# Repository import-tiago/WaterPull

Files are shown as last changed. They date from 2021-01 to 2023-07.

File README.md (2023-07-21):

# Water Pull
WaterPull is an electronic polymer dryer focused on removing moisture from 3D printer filaments. It has control and adjustment of temperature and curing time, internal air circulation and alarms.

## PCB Preview
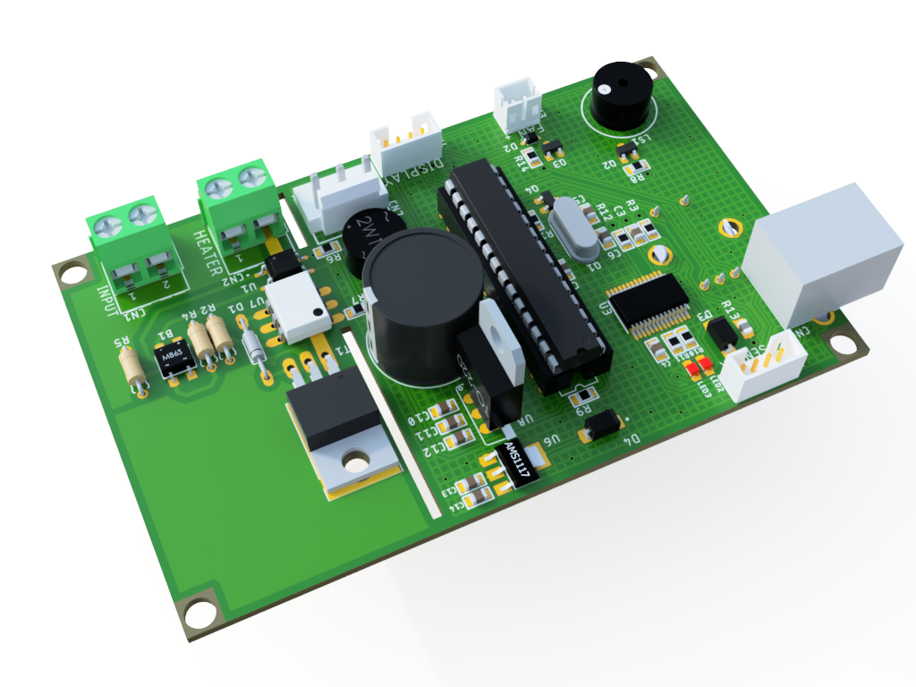
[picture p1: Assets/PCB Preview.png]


## Enclosure Preview
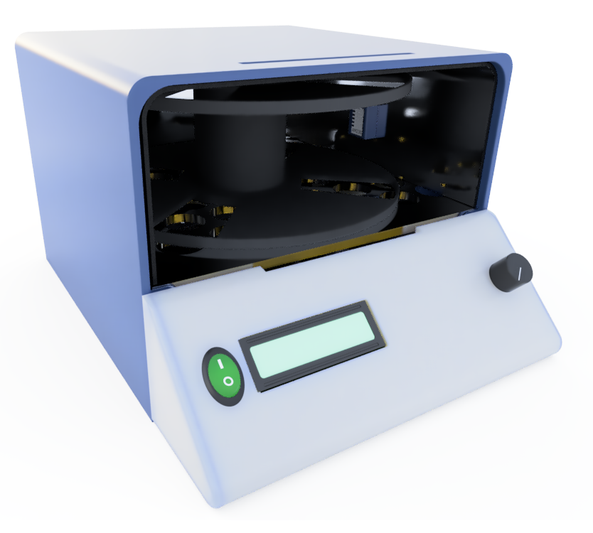
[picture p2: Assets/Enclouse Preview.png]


## Schematic
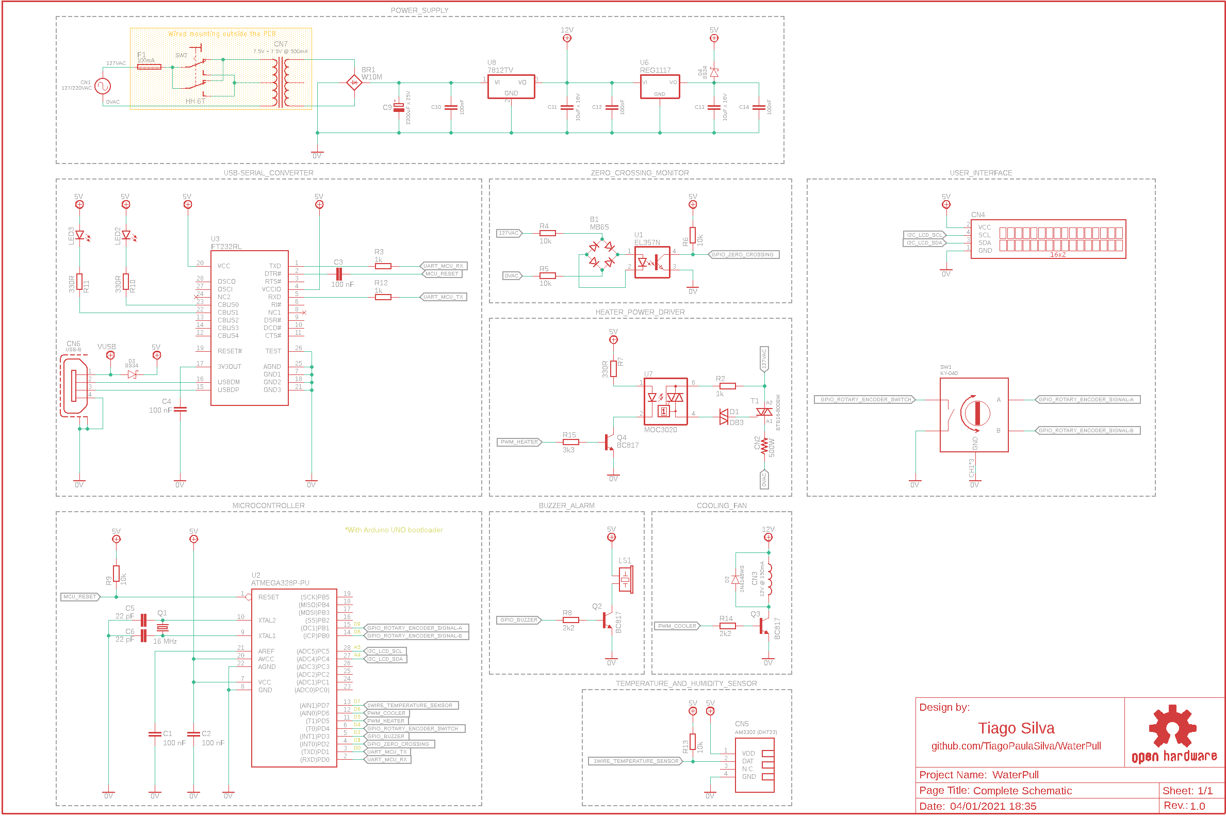
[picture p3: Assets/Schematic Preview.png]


### Contributing
0. Give this project a :star:
1. Create an issue and describe your idea.
2. [Fork it](https://github.com/import-tiago/WaterPull/fork).
3. Create your feature branch (`git checkout -b my-new-feature`).
4. Commit your changes (`git commit -a -m "Added feature title"`).
5. Publish the branch (`git push origin my-new-feature`).
6. Create a new pull request.
7. Done! :heavy_check_mark:

### License Information
<br /><span xmlns:dct="http://purl.org/dc/terms/" property="dct:title">ChristmasTree</span> by <a xmlns:cc="http://creativecommons.org/ns#" href="https://github.com/import-tiago" property="cc:attributionName" rel="cc:attributionURL">Tiago Silva</a> is licensed under a <a rel="license" href="http://creativecommons.org/licenses/by-sa/4.0/">Creative Commons Attribution-ShareAlike 4.0 International License</a>.<br />Permissions beyond the scope of this license may be available at <a xmlns:cc="http://creativecommons.org/ns#" href="https://twitter.com/import_tiago" rel="cc:morePermissions">tiagodepaulasilva@gmail.com</a>.

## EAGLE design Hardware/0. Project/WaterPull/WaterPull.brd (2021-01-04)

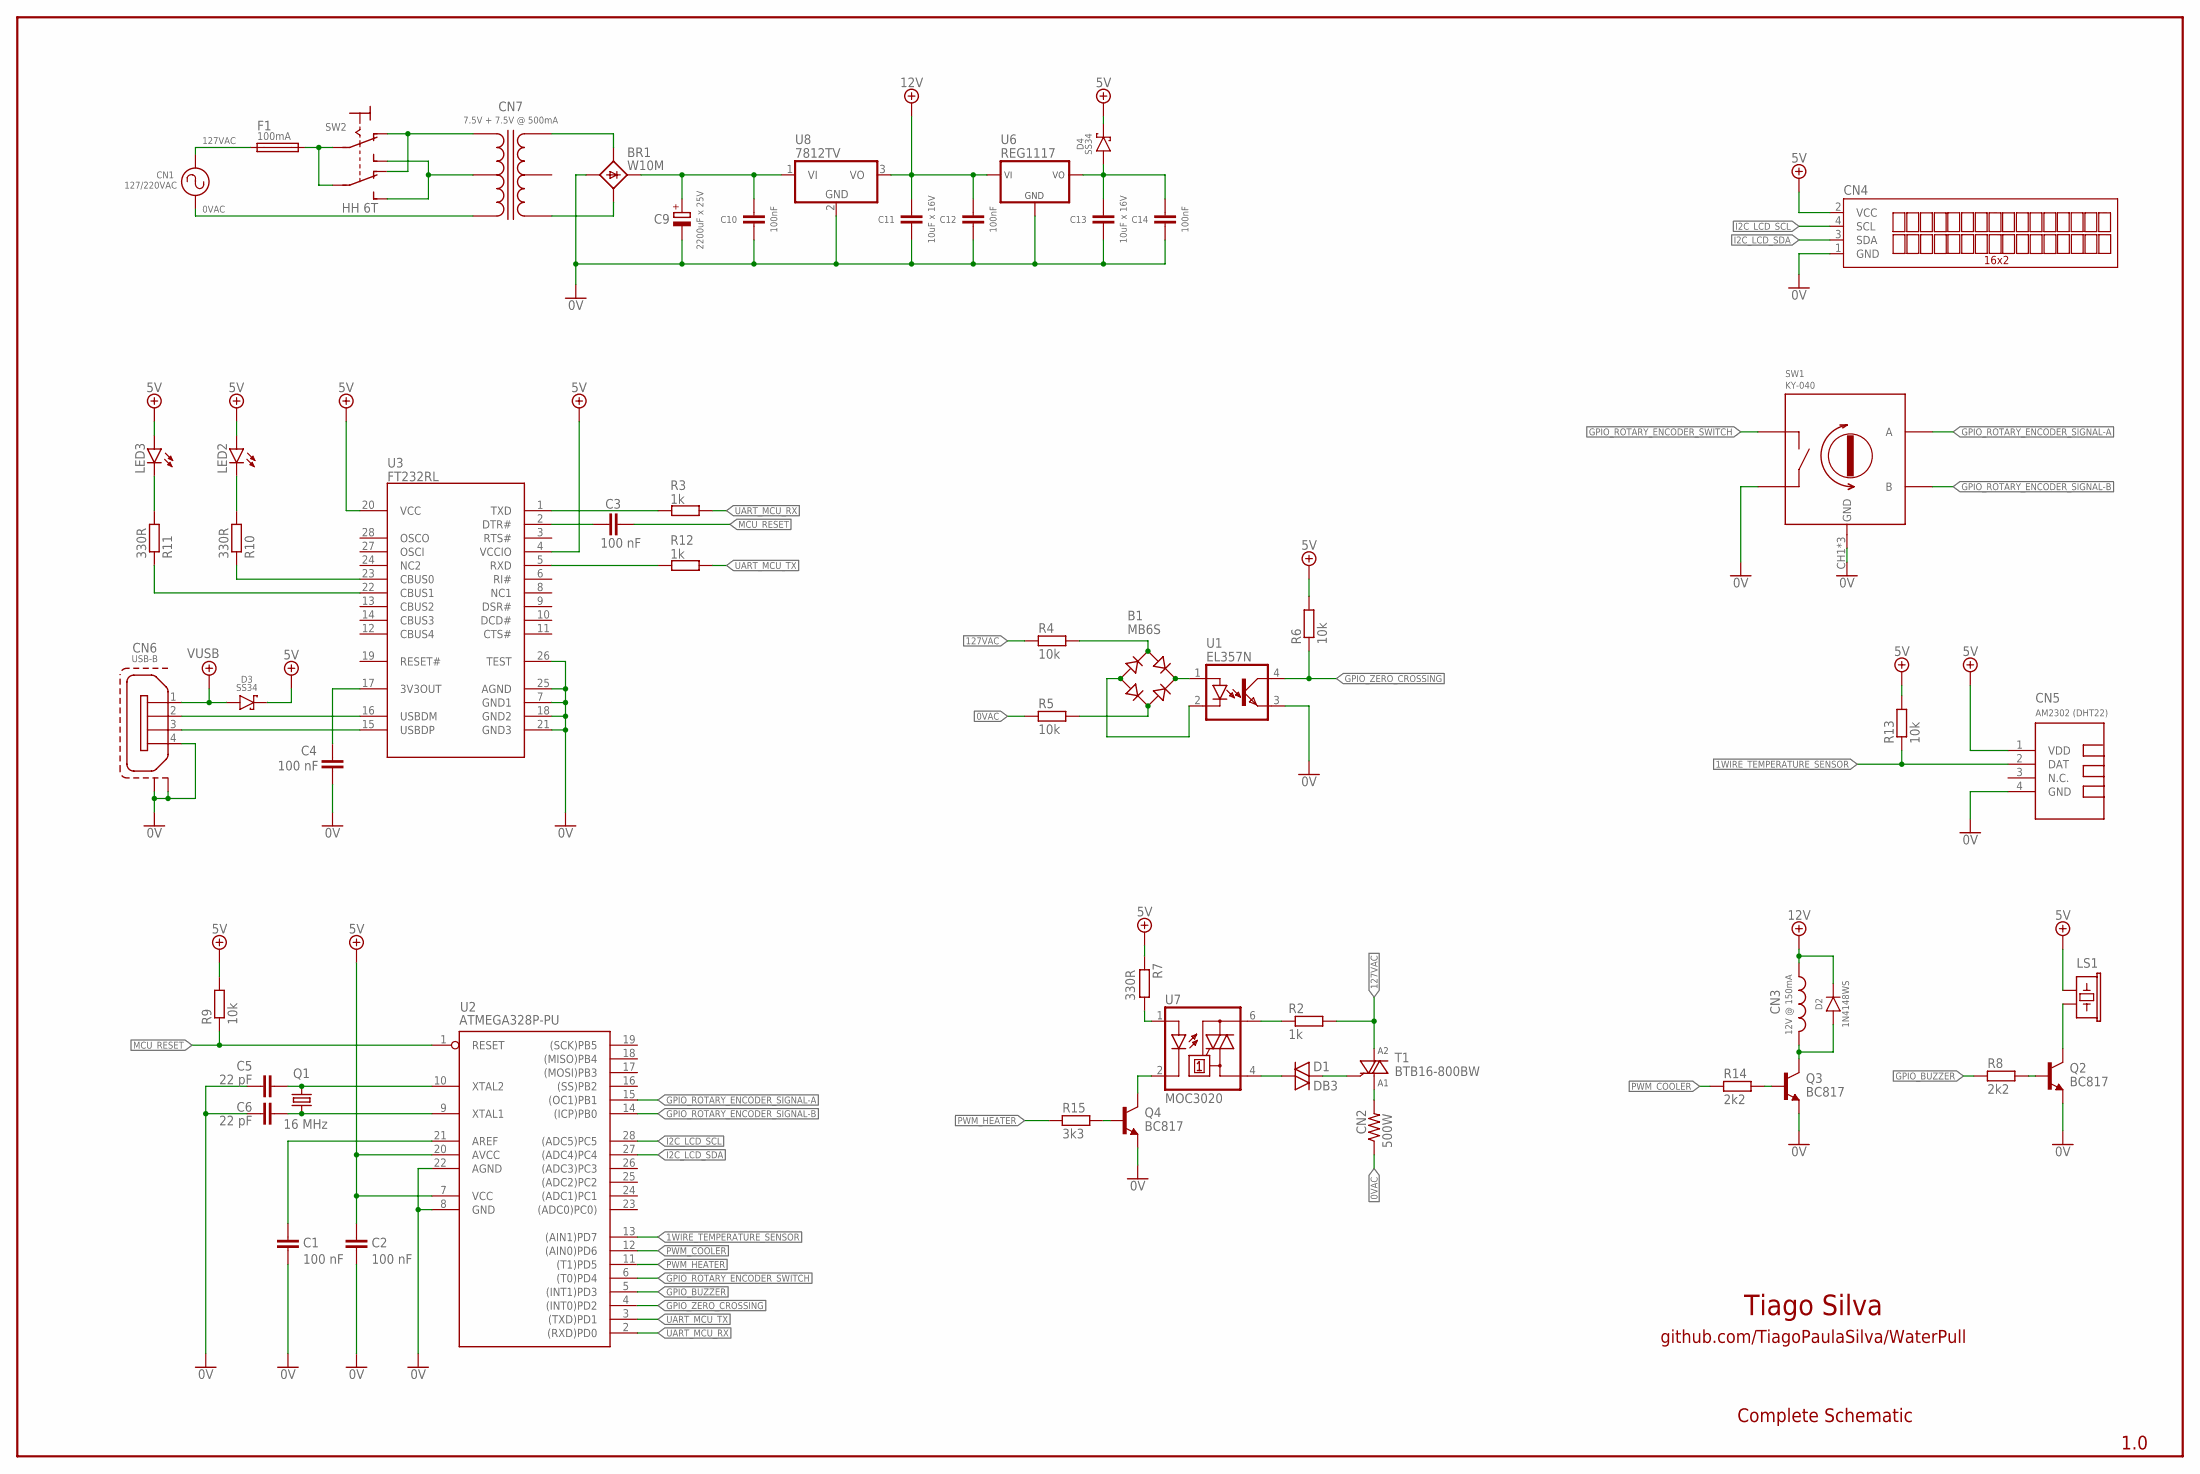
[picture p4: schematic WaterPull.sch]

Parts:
B1: MB6S; SOIC-4
BR1: W10M; DIOB_W005M
C1, C2, C3, C4: 100 nF; C0805
C5, C6: 22 pF; C0805
C9: 2200uF x 25V; E7,5-16
C10, C12, C14: 100nF; C0805
C11, C13: 10uF x 16V; C0805
CN1: 127/220VAC; AK500/2-H
CN2: 500W; AK500/2-H
CN3: 12V @ 150mA; JST-PH2
CN4: TUXGR_16X2_R2
CN5: AM2302 (DHT22); TEMP-HUM-SENSOR-DHT22
CN6: USB-B
CN7: 7.5V + 7.5V @ 500mA; 3PINS
D1: DB3; DO35-10
D2: 1N4148WS; SOD323F
D3, D4: SS34; DO214AB
LED2, LED3: LEDCHIPLED_0805; CHIPLED_0805
LS1: BUZZER-PTH; BUZZER-12MM
Q1: 16 MHz; HC49/S
Q2, Q3, Q4: BC817; SOT23-BEC
R2: 1k; 0207/7
R3, R12: 1k; R0805
R4, R5: 10k; 0207/7
R6, R9, R13: 10k; R0805
R7, R10, R11: 330R; R0805
R8, R14: 2k2; R0805
R15: 3k3; R0805
SW1: KY-040
T1: BTB16-800BW; TO220BH
U1: EL357N; SOP254P700X200-4N
U2: ATMEGA328P-PU; DIL28-3
U3: FT232RL; SSOP28
U6: REG1117; SOT223
U7: MOC3020; DIL06
U8: 7812TV; TO220V

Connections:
0V: BR1.-, C1.2, C2.2, C4.1, C5.1, C6.1, C9.-, C10.2, C11.2, C12.2, C13.2, C14.2, CN4.1 (GND), CN5.4 (GND), CN6.4, CN6.M1 (S1), CN6.M2 (S2), Q2.E, Q3.E, Q4.E, SW1.CH1 (GND), SW1.CH2 (GND), SW1.GND, SW1.SW2, U1.3 (E), U2.8 (GND), U2.22 (AGND), U3.7 (GND1), U3.18 (GND2), U3.21 (GND3), U3.25 (AGND), U3.26 (TEST), U6.1 (GND), U8.2 (GND)
0VAC: CN1.1, CN2.1, R5.1
1WIRE_TEMPERATURE_SENSOR: CN5.2 (DAT), R13.1, U2.13 ((AIN1)PD7)
5V: C2.1, CN4.2 (VCC), CN5.1 (VDD), D3.C (K), D4.C (K), LED2.A, LED3.A, LS1.+ (1), R6.2, R7.1, R9.2, R13.2, U2.7 (VCC), U2.20 (AVCC), U3.4 (VCCIO), U3.20 (VCC)
12VDC: C11.1, C12.1, CN3.2 (1), D2.C (K), U6.3 (VIN), U8.3 (VO)
127VAC: CN1.2, R2.2, R4.1, T1.T2 (A2)
A1: CN2.2, T1.T1 (A1)
AREF: C1.1, U2.21 (AREF)
GND1: BR1.~B (AC2), CN7.3
GPIO_BUZZER: R8.1, U2.5 ((INT1)PD3)
GPIO_ROTARY_ENCODER_SIGNAL-A: SW1.A, U2.15 ((OC1)PB1)
GPIO_ROTARY_ENCODER_SIGNAL-B: SW1.B, U2.14 ((ICP)PB0)
GPIO_ROTARY_ENCODER_SWITCH: SW1.SW1, U2.6 ((T0)PD4)
GPIO_ZERO_CROSSING: R6.1, U1.4 (C), U2.4 ((INT0)PD2)
I2C_LCD_SCL: CN4.4 (SCL), U2.28 ((ADC5)PC5)
I2C_LCD_SDA: CN4.3 (SDA), U2.27 ((ADC4)PC4)
MCU_RESET: C3.1, R9.1, U2.1 (RESET)
unnamed: D1.A (1), U7.4 (A1)
unnamed: D1.C (2), T1.G
unnamed: B1.~1 (AC1), R4.2
unnamed: B1.~2 (AC2), R5.2
unnamed: B1.+, U1.1 (A)
unnamed: B1.-, U1.2 (K)
unnamed: R3.2, U3.1 (TXD)
unnamed: R2.1, U7.6 (A2)
unnamed: R7.2, U7.1 (A)
unnamed: LS1.- (2), Q2.C
unnamed: R12.2, U3.5 (RXD)
unnamed: BR1.+, C9.+, C10.1, U8.1 (VI)
unnamed: Q4.B, R15.2
unnamed: Q4.C, U7.2 (C)
unnamed: C13.1, C14.1, D4.A, U6.2 (VOUT), U6.4 (VOUT)
unnamed: C3.2, U3.2 (DTR#)
unnamed: R10.1, U3.23 (CBUS0)
unnamed: LED2.C, R10.2
unnamed: LED3.C, R11.2
unnamed: C5.2, Q1.2, U2.10 (XTAL2)
unnamed: C6.2, Q1.1, U2.9 (XTAL1)
unnamed: R11.1, U3.22 (CBUS1)
unnamed: C4.2, U3.17 (3V3OUT)
unnamed: CN6.2, U3.16 (USBDM)
unnamed: CN6.3, U3.15 (USBDP)
unnamed: Q2.B, R8.2
unnamed: CN3.1 (2), D2.A, Q3.C
unnamed: Q3.B, R14.2
unnamed: BR1.~A (AC1), CN7.1
PWM_COOLER: R14.1, U2.12 ((AIN0)PD6)
PWM_HEATER: R15.1, U2.11 ((T1)PD5)
UART_MCU_RX: R3.1, U2.2 ((RXD)PD0)
UART_MCU_TX: R12.1, U2.3 ((TXD)PD1)
VUSB: CN6.1, D3.A

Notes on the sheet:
Tiago Silva
github.com/TiagoPaulaSilva/WaterPull
1.0
Complete Schematic

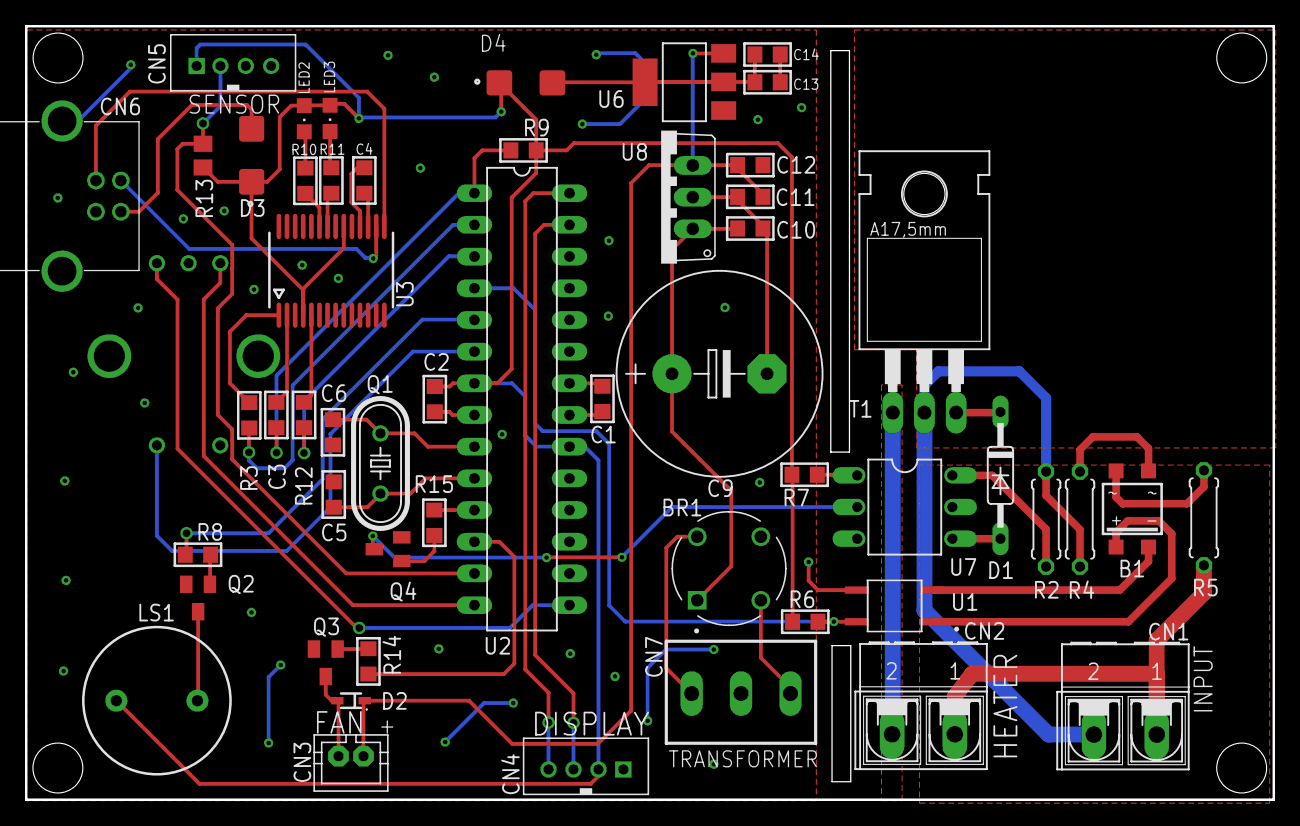
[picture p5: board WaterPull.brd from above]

Board: 2 copper layers, 100.0 x 62.0 mm, 54 parts (1 on the bottom side), 51 nets.

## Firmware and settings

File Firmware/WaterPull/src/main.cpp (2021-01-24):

// Native Libraries
#include <Arduino.h>

// ANSI C Libraries
#include <stdlib.h>

// Application Libraries
#include <RotaryEncoder.h>
#include <TimerOne.h>
#include "Adafruit_Sensor.h"
#include <DHT.h>
#include <LiquidCrystal_I2C.h>

// Hardware Definitions
#define Temperature_Sensor_Pin 7

#define Rotary_Enconder_Clock_Pin   8
#define Rotary_Enconder_Data_Pin 	9
#define Rotary_Enconder_Switch_Pin  4
#define Zero_Crossing_Pin 			2	
#define Buzzer_Pin 					3
#define Heater_Pin 					5
#define Cooler_Pin 					6
#define Zero_Crossing_Interrupt     0



// Application Constants
#define STARTING_MESSAGE_TIME 250
#define TEXT_BLINK_TIME 	  300
#define ARROW_DOWN 			  0
#define ARROW_RIGHT 		  1

#define SOUND_ALARM_NUMBER_BEEP 	  3
#define SOUND_ALARM_PERIOD_BEEP 	  400



// Global Objects
RotaryEncoder RotaryEnconder(Rotary_Enconder_Data_Pin, Rotary_Enconder_Clock_Pin);
DHT AmbientSensor(Temperature_Sensor_Pin, DHT22);
LiquidCrystal_I2C LCD(0x27, 16, 2); //I2C address = 0x27

// Global Variables
int Last_Rotary_Position = 0;
float Current_Humidity = 0;
float Current_Temperature = 0;
unsigned int Current_Cure_Time = 0;

float Setpoint_Temperature = 50;
unsigned int Setpoint_Cure_Time = 180;

unsigned long Current_Millis = 0;
unsigned long Previous_Millis = 0;
unsigned long ISR_Tick = 0;

volatile int Current_Rotary_Position = 0;


volatile boolean zero_cross = false;

int Heater_Power = 1; //0-255 (duty cycle)


bool Toggle = false;

bool increment = false;


byte button;

// LCD
byte DownArrow[] = {
	B00100,
	B00100,
	B00100,
	B00100,
	B00100,
	B11111,
	B01110,
	B00100};

byte RightArrow[] = {
	B00000,
	B10000,
	B11000,
	B11100,
	B11110,
	B11100,
	B11000,
	B10000};

// Finite State Machine States
typedef enum
{
	STARTING = 0,
	TEMPERATURE_ADJUSTMENT,
	CURE_TIME_ADJUSTMENT,
	HEATING,
	WAITING_START,
	FINISH_CURE
} StatesFSM;

StatesFSM stateFSM = STARTING;

// Functions Prototypes
void Change_Machine_State_to(StatesFSM New_State);
void Trigger_Buzzer_Alarm();
void Cure_Time_Decrement();

void Read_Rotary_Enconder()
{
	if (digitalRead(Rotary_Enconder_Switch_Pin) == 0)	
	{
		
		while (digitalRead(Rotary_Enconder_Switch_Pin) == 0)
			delay(3);

		Serial.println("Pressed");

		if(stateFSM == TEMPERATURE_ADJUSTMENT) {			
			Change_Machine_State_to(CURE_TIME_ADJUSTMENT);			
		}

		else if(stateFSM == CURE_TIME_ADJUSTMENT) {			
		 	Change_Machine_State_to(WAITING_START);
		}

		else if(stateFSM == WAITING_START) {	
			Current_Cure_Time = Setpoint_Cure_Time;					
		 	Change_Machine_State_to(HEATING);
		}

		else
			Serial.println("F");			
	}

	RotaryEnconder.tick();
	Current_Rotary_Position = RotaryEnconder.getPosition();

	if (Current_Rotary_Position != Last_Rotary_Position)
	{

		//if ( (Current_Rotary_Position == 1) && (stateFSM != TEMPERATURE_ADJUSTMENT) &&  (stateFSM != CURE_TIME_ADJUSTMENT) )
		if ( (stateFSM != TEMPERATURE_ADJUSTMENT) &&  (stateFSM != CURE_TIME_ADJUSTMENT) )
			Change_Machine_State_to(TEMPERATURE_ADJUSTMENT);
		
		//else if (Current_Rotary_Position == 0 && (stateFSM != TEMPERATURE_ADJUSTMENT) &&  (stateFSM != CURE_TIME_ADJUSTMENT) )
		else if ( (stateFSM != TEMPERATURE_ADJUSTMENT) &&  (stateFSM != CURE_TIME_ADJUSTMENT) )
			Change_Machine_State_to(CURE_TIME_ADJUSTMENT);
		
		else if (stateFSM == TEMPERATURE_ADJUSTMENT) {		
			
			Current_Rotary_Position > Last_Rotary_Position ? increment = true : increment = false;
					
			if(increment)
				Setpoint_Temperature++;
			else
			{
				if(Setpoint_Temperature > 30)
					Setpoint_Temperature--;
			}
		}

		else if (stateFSM == CURE_TIME_ADJUSTMENT) {
			Current_Rotary_Position > Last_Rotary_Position ? increment = true : increment = false;
					
			if(increment)
				Setpoint_Cure_Time += 10;
			else
			{
				if(Setpoint_Cure_Time >= 10)
				Setpoint_Cure_Time -= 10;
			}
			//Current_Rotary_Position = 0;
		}

		Serial.print(Current_Rotary_Position);
		Serial.println();
		Last_Rotary_Position = Current_Rotary_Position;
	}
}

void Read_Ambient_Sensor()
{
	Current_Humidity = AmbientSensor.readHumidity();
	Current_Temperature = AmbientSensor.readTemperature();
}

void IST_TIMER_0(void)
{
	Read_Rotary_Enconder();
	Read_Ambient_Sensor();
	Cure_Time_Decrement();

	
}

void Cure_Time_Decrement()
{
	if(stateFSM == HEATING) {
		ISR_Tick++;
		
		if(ISR_Tick >= 60000) {

			ISR_Tick = 0;
			Current_Cure_Time--;

			if(round(Current_Cure_Time) <= 0) {								
				Change_Machine_State_to(FINISH_CURE);
			}
		}
	}
}

void Trigger_Buzzer_Alarm()
{
	int beep = SOUND_ALARM_NUMBER_BEEP;
		
	do {
		if (millis() - Previous_Millis > SOUND_ALARM_PERIOD_BEEP)
		{
			Previous_Millis = millis();
			
			if(Toggle)
			{
				Toggle = false;
				digitalWrite(Buzzer_Pin, HIGH);				
			}
			else
			{
				Toggle = true;
				digitalWrite(Buzzer_Pin, LOW);
				beep--;
			}
		}
	}while(beep > 0);
}

void Change_Machine_State_to(StatesFSM New_State)
{

	switch (New_State)
	{

	case STARTING:
		stateFSM = STARTING;
		break;

	case HEATING:
		stateFSM = HEATING;
		break;

	case TEMPERATURE_ADJUSTMENT:
		stateFSM = TEMPERATURE_ADJUSTMENT;
		break;

	case CURE_TIME_ADJUSTMENT:
		stateFSM = CURE_TIME_ADJUSTMENT;
		break;

	case WAITING_START:
		stateFSM = WAITING_START;
		break;

	case FINISH_CURE:
		stateFSM = FINISH_CURE;
		break;		
	}
}

void Show_Current_Temperature()
{

	LCD.setCursor(0, 0);
	LCD.print(Current_Temperature, 1);
	LCD.print((char)223);
	LCD.print("C");
}

void Show_Temperature_Setpont()
{
	LCD.setCursor(12, 0);	
	LCD.print(Setpoint_Temperature, 0);
	LCD.print((char)223);
	LCD.print("C");
}

void Show_Current_Cure_Time()
{	
	int hours = Current_Cure_Time / 60;
	int mins = round((((Current_Cure_Time / 60.0)) - hours) * 60);
	
	char array_buf[10];
	if(mins < 10)
		sprintf(array_buf, "%dh0%d", hours, mins);
	else	
		sprintf(array_buf, "%dh%d", hours, mins);

	LCD.setCursor(0, 1);
	LCD.print(array_buf);
	LCD.print(" ");
}

void Show_Cure_Time_Setpont()
{
	int hours = Setpoint_Cure_Time / 60;
	int mins = round((((Setpoint_Cure_Time / 60.0)) - hours) * 60);

	if(hours <= 0 && mins <= 0)
	{
		hours = 0;	
		mins = 1;
		Setpoint_Cure_Time = 1;
	}
	
	
	char array_buf[10];
	if(mins < 10)
		sprintf(array_buf, "%dh0%d", hours, mins);
	else	
		sprintf(array_buf, "%dh%d", hours, mins);	
	
	LCD.setCursor(12, 1);
	LCD.print(array_buf);
}

void Show_Start_Button() {	
	LCD.setCursor(1, 1);
	LCD.print("START");	
}

void Hide_Start_Button() {	
	LCD.setCursor(1, 1);
	LCD.print("     ");	
}

void Run_SFM()
{
	switch (stateFSM)
	{
		case STARTING: {
			LCD.setCursor(3, 0);
			LCD.print("Water Pull");
			LCD.setCursor(1, 1);
			LCD.print("Filament Dryer");
			delay(STARTING_MESSAGE_TIME);
			LCD.clear();

			Change_Machine_State_to(WAITING_START);
			break;
		}

		case WAITING_START: {
			
			LCD.setCursor(11, 0); LCD.write(ARROW_RIGHT);
			LCD.setCursor(11, 1); LCD.write(ARROW_RIGHT);

			if (millis() - Previous_Millis > TEXT_BLINK_TIME)
			{
				Previous_Millis = millis();
				
				if(Toggle)
				{
					Toggle = false;					
					Show_Current_Temperature();					
					Show_Temperature_Setpont();

					LCD.setCursor(0, 1); LCD.write(ARROW_RIGHT);
					Show_Start_Button();

					Show_Cure_Time_Setpont();
				}
				else
				{
					Toggle = true;			
					Show_Current_Temperature();					
					Show_Temperature_Setpont();

					LCD.setCursor(0, 1); LCD.print(" ");
					Show_Start_Button();

					Show_Cure_Time_Setpont();
				}
			}
			break;
		}

		case HEATING: {
			digitalWrite(Cooler_Pin, HIGH);
			if (millis() - Previous_Millis > TEXT_BLINK_TIME)
			{
				Previous_Millis = millis();
				
				if(Toggle)
				{
					Toggle = false;		
					Show_Current_Temperature();
					LCD.setCursor(11, 0); LCD.write(ARROW_RIGHT);
					Show_Temperature_Setpont();
					LCD.setCursor(5, 1); LCD.write(ARROW_DOWN);
					Show_Current_Cure_Time();
					LCD.setCursor(11, 1); LCD.write(ARROW_RIGHT);
					Show_Cure_Time_Setpont();
				}
				else
				{
					Toggle = true;
					Show_Current_Temperature();
					LCD.setCursor(11, 0); LCD.write(ARROW_RIGHT);
					Show_Temperature_Setpont();
					LCD.setCursor(5, 1); LCD.print(" ");
					Show_Current_Cure_Time();
					LCD.setCursor(11, 1); LCD.write(ARROW_RIGHT);
					Show_Cure_Time_Setpont();
				}
			}

			if(zero_cross) {
				zero_cross = false;
				analogWrite(Heater_Pin, Heater_Power);    
				delayMicroseconds(500);
				digitalWrite(Heater_Pin, LOW);

			}

			break;
		}
		
		case TEMPERATURE_ADJUSTMENT: {			

			if (millis() - Previous_Millis > TEXT_BLINK_TIME)
			{
				Previous_Millis = millis();
				
				if(Toggle)
				{
					Toggle = false;
					LCD.setCursor(0, 1); LCD.print(" ");
					Show_Current_Temperature();
					LCD.setCursor(11, 0); LCD.write(ARROW_RIGHT);
					Show_Temperature_Setpont();
					Hide_Start_Button();
					Show_Cure_Time_Setpont();
				}
				else
				{
					Toggle = true;
					Show_Current_Temperature();
					LCD.setCursor(11, 0); LCD.print(" ");
					Show_Temperature_Setpont();
					Hide_Start_Button();
					Show_Cure_Time_Setpont();
				}
			}

			break;
		}

		case CURE_TIME_ADJUSTMENT: {		

			if (millis() - Previous_Millis > TEXT_BLINK_TIME)
			{
				Previous_Millis = millis();
				
				if(Toggle)
				{
					Toggle = false;		
					Show_Current_Temperature();
					LCD.setCursor(11, 1); LCD.write(ARROW_RIGHT);
					Show_Temperature_Setpont();
					Hide_Start_Button();
					Show_Cure_Time_Setpont();
				}
				else
				{
					Toggle = true;			
					Show_Current_Temperature();
					LCD.setCursor(11, 1); LCD.print(" ");
					Show_Temperature_Setpont();
					Hide_Start_Button();
					Show_Cure_Time_Setpont();
				}
			}

		break;
		}
	
		case FINISH_CURE: {
			digitalWrite(Cooler_Pin, LOW);
			Change_Machine_State_to(WAITING_START);
			Trigger_Buzzer_Alarm();
			break;
		}
	}
}

void ISR_GPIO() {
  zero_cross = true;
}

void setup()
{
	Serial.begin(9600);
	Serial.println("START");

	pinMode(Rotary_Enconder_Clock_Pin, INPUT_PULLUP);
	pinMode(Rotary_Enconder_Data_Pin, INPUT_PULLUP);
	pinMode(Rotary_Enconder_Switch_Pin, INPUT_PULLUP);

	pinMode(Buzzer_Pin, OUTPUT);
	digitalWrite(Buzzer_Pin, LOW);	
	
	pinMode(Cooler_Pin, OUTPUT);
	digitalWrite(Cooler_Pin, LOW);

	pinMode(Heater_Pin, OUTPUT);
	digitalWrite(Heater_Pin, HIGH);

	pinMode(Heater_Pin, OUTPUT);
	digitalWrite(Heater_Pin, LOW);

	Timer1.initialize(1000); // 1ms
	Timer1.attachInterrupt(IST_TIMER_0);

	LCD.init();
	LCD.setBacklight(HIGH);

	LCD.createChar(0, DownArrow);
	LCD.createChar(1, RightArrow);	  
  
  	attachInterrupt(Zero_Crossing_Interrupt, ISR_GPIO, RISING);

	AmbientSensor.begin();
}


void loop()
{
	Run_SFM();	
}

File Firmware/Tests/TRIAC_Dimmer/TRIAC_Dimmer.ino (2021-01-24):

int PWM_Heater_Pin = 5;
int Zero_Crossing_Pin = 2;
int Zero_Crossing_Interrupt = 0;

volatile boolean zero_cross = false;

int Heater_Power = 1; //0-255 (duty cycle)

void setup() {
  
  Serial.begin(9600);
  Serial.println("--- START ---");

  pinMode(PWM_Heater_Pin, OUTPUT);
  
  attachInterrupt(Zero_Crossing_Interrupt, ISR_GPIO, RISING);
}

void loop() {

  if(zero_cross) {
    zero_cross = false;
    analogWrite(PWM_Heater_Pin, Heater_Power);    
    delayMicroseconds(500);
    digitalWrite(PWM_Heater_Pin, LOW);

  }
  
}

void ISR_GPIO() {
  zero_cross = true;
}

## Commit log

2021-01-03 WIP PCB layout
    [WaterPull.brd]
2021-01-04 Schematic 1.0 - DONE
    [WaterPull.brd, WaterPull.sch]
2021-01-04 Gerber files from schematic 1.0 generated
2021-01-04 Schematic 1.0 preview added
    [WaterPull.sch]
2021-01-04 PCB preview added
2021-01-04 Enclosure preview added

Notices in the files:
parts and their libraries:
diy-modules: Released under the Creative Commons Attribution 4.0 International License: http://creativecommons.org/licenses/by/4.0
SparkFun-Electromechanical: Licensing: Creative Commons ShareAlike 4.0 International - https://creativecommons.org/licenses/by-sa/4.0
